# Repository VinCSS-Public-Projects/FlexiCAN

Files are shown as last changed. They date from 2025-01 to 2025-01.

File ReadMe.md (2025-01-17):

# FlexiCAN
The FlexiCAN device, developed by VinCSS, is an innovative automotive CAN solution designed for flexibility and ease of use. It features a unique software-controlled hot-swappable semiconductor switching matrix, enabling users to dynamically reconfigure the CAN_H and CAN_L pins of the CAN bus to any pin on the OBD-II port. This eliminates the need for proprietary connection cables, allowing seamless routing to non-standard or hidden CAN bus ports present on the OBD-II interface. Key highlights include software-configurable termination resistors (120Ω), support for CANFD up to 5 Mbit/s, and compatibility with both 11-bit (CAN 2.0A) and 29-bit (CAN 2.0B active) identifiers. The device supports high-speed CAN (ISO 11898-2 compliant) up to 1 Mbit/s and is fully compatible with Linux and CANSocket for robust integration. Its plug-and-play installation and fast, flexible command execution make it user-friendly, while the upcoming silent mode ensures non-intrusive analysis capabilities, making it ideal for automotive diagnostics and research applications.

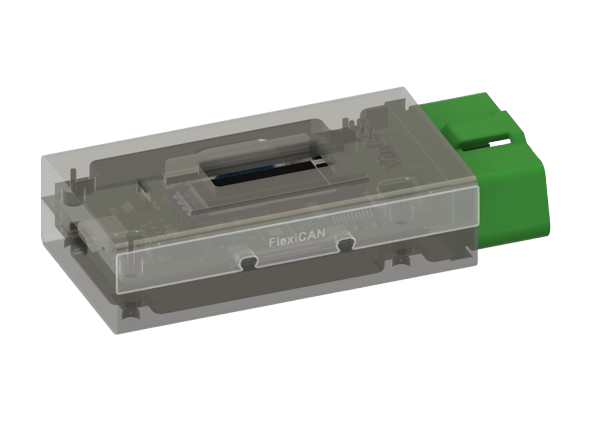
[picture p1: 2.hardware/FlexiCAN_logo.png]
FlexiCAN


# Key Features

• Flexibly Configure the Connection Between OBD-II and the CAN Device

• Software-configurable termination resistor (120Ω).

• Fast and flexible access to commands through COM

• Quick and straightforward plug-and-play installation.

• Supports CAN FD, with speeds up to 5 Mbit/s.

• Compatible with both 11-bit (CAN 2.0A) and 29-bit (CAN 2.0B active) identifiers.

• Fully compatible with Linux and CAN Socket.

• High-speed CAN connection (ISO 11898-2 compliant) with data rates up to 1 Mbit/s.

• Silent mode support for analysis tools – allows monitoring of the bus without interference (coming soon).

Full detail please check the document: [FlexiCAN-User-Manual-English.pdf](4.docs/FlexiCAN-User-Manual-English.pdf)
# Community & Support

We welcome contributions from the community! Please follow these steps:

1. Fork the repository.

2. Create a new branch (git checkout -b feature-branch-name).

3. Commit your changes (git commit -m "Description of changes").

4. Push to the branch (git push origin feature-branch-name).

5. Open a pull request.

If you encounter any problems, please open an issue. We will check and response as fast as possible.

## Hardware

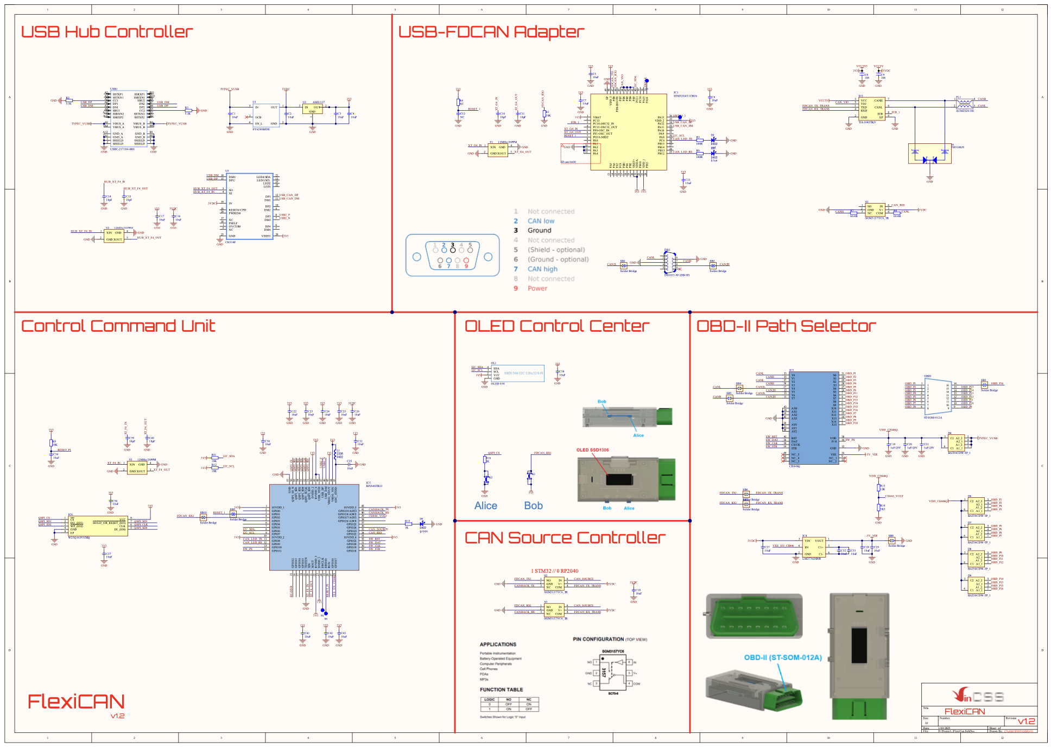
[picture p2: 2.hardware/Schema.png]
Schema


## Firmware

There are two controllers in FlexiCAN: RP2040 and STM32.

RP2040 is to control FlexiCAN & OBD-II switch.

STM32 is to control CAN interface

Source code of STM32 we use from this link https://github.com/candle-usb/candleLight_fw

# License 

FlexiCAN is fully open source.

All software, unless otherwise noted, is dual licensed under Apache 2.0 and MIT. You may use FlexiCAN software under the terms of either the Apache 2.0 license or MIT license.

All hardware, unless otherwise noted, is dual licensed under CERN and CC-BY-SA. You may use FlexiCAN hardware under the terms of either the CERN 1.2 license or CC-BY-SA 4.0 license.

THE SOFTWARE IS PROVIDED "AS IS", WITHOUT WARRANTY OF ANY KIND, EXPRESS OR IMPLIED, INCLUDING BUT NOT LIMITED TO THE WARRANTIES OF MERCHANTABILITY, FITNESS FOR A PARTICULAR PURPOSE AND NONINFRINGEMENT. IN NO EVENT SHALL THE AUTHORS OR COPYRIGHT HOLDERS BE LIABLE FOR ANY CLAIM, DAMAGES OR OTHER LIABILITY, WHETHER IN AN ACTION OF CONTRACT, TORT OR OTHERWISE, ARISING FROM, OUT OF OR IN CONNECTION WITH THE SOFTWARE OR THE USE OR OTHER DEALINGS IN THE SOFTWARE.

# Acknowledgment

FlexiCAN is built upon the foundation of many other excellent open-source projects. We would like to express our gratitude to the following contributors:

Thank you [@sakumisu](https://github.com/sakumisu) for the projects:
- [CherryShell](https://github.com/cherry-embedded/CherrySH), a tiny shell specifically designed for embedded applications.
- [CherryUSB](https://github.com/cherry-embedded/CherryUSB), a tiny, beautiful, and portable USB host and device stack for embedded systems with USB IP.

Thank you [@Egahp](https://github.com/Egahp) for the [CherryRingBuffer](https://github.com/cherry-embedded/CherryRB) project, an efficient and easy-to-use ring buffer, especially with DMA support

Thank you [@marckleinebudde](https://github.com/marckleinebudde) and the [candleLight](https://github.com/candle-usb/candleLight_fw) development team for creating such an incredibly useful project

# Ethical and Responsible Use

This tool, FlexiCAN, is developed for educational and ethical testing purposes only.  Any misuse or illegal use of this tool is strictly prohibited. The creator of FlexiCAN  assumes no liability and is not responsible for any misuse or damage caused by this tool. 
Users are required to comply with all applicable laws and regulations in their jurisdiction regarding network testing and ethical hacking.

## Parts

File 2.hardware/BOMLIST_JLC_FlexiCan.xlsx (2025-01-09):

Comment | Description | Designator | Footprint | LibRef | Quantity | JLCPCB Part #
10uF | Capacitor | C1, C2, C3, C4, C5, C6, C7, C13, C16, C17, C18, C22, C23, C24, C25, C26, C27, C28, C29, C30, C31, C32, C33, C34, C35, C36, C37, C38, C41, C42, C43 | CAP_0402 | C_0402 | 31 | C15525
104 | Cap SMD | C8, C9 | CAP_0402 | CM | 2 | C1525
18pF | Capacitor | C10, C11, C14, C15, C39, C40 | CAP_0402 | C_0402 | 6 | C1549
NC | Capacitor | C12 | CAP_0402 | C_0402 | 1 | no soldering
1uF/25V | Capacitor | C19, C20, C21 | CAP_0402 | C_0402 | 3 | C52923
red | LED | D1 | LED_0402_RED | LED_0402 | 1 | C264407
blue | LED | D2 | LED_0402_BLUE | LED_0402 | 1 | C131223
PESD1CAN,215 | TVS DIODE 5V 14V SOT23 | D3 | SOT23-3 | PESD5V0S2BT,215 | 1 | C15771
BAT54CDW-TP_1 | Schottky Diode | D4, D6, D7, D8, D9 | SOT65P222X120-6N | BAT54CDW-TP_1 | 5 | C5240639
green | LED | D5 | LED_0402_GREEN | LED_0402 | 1 | C20613596
DS1033-9F (DB-9F) | DS1033-9F (DB-9F) Female | DB1 | DB-9 DS1033-9F | DB9-F | 1 | C3020564
ACM2520-301 | Common Mode Filters | FL1 | ACM25203012P | ACM2520-301-2PL-TL01_1 | 1 | C76577
STM32G431CBU6 | Integrated Circuit | IC1 | QFN50P700X700X65-49N-D | STM32G431CBU6 | 1 | C529356
TJA1042TK/3 | https://item.taobao.com/item.htm?id=715328337189&ns=1&abbucket=13 | IC2 | SON65P300X300X100-9N | SIT1044QTK/3 | 1 | C131480
CH446Q | Integrated Circuit | IC3 | QFP80P1350X1350X150-44N | CH446Q | 1 | C109471
LM2776DBVR | Integrated Circuit | IC4 | SOT95P280X145-6N | LM2776DBVR | 1 | C69527
RP2040TR13 | Integrated Circuit | IC5 | RP2040TR13 | RP2040TR13 | 1 | C2040
W25Q16JVUXIQ | Integrated Circuit | IC6 | SON50P300X200X60-9N | W25Q16JVUXIQ | 1 | C2843335
TACT 4P | Button | K1, K2 | ButtonTACT_3.5*3.55_90 | ButtonTACT | 2 | C79167
H0402 | Inductor | L1 | IND_0402Q | Ind_0402 | 1 | C14709
ST-SOM-012A | ST-SOM-012A OBD II Connector | OBD1 | ST-SOM-012A | ST-SOM-012A | 1 | https://www.setolink.com/pcb-obdii-16-pin-male-connector-core-st-som012a.html
OLED 0.91 | HS HS91L02W2C01 SSD1306 I2C 128x32 0.91 - Organic Light Emitting Diode Display Screen ROHS | OL1 | OLED 0.91 I2C | OLED 0.91 128*32 | 1 | C5248081
10K | Resistor R1/4W, Resistor | R1, R9, R11, R12 | RES_0402 | R, R-0402 | 4 | C25744
5.1K | Resistor | R2, R3 | RES_0402 | R-0402 | 2 | C25905
NC | Resistor | R4 | RES_0402 | R-0402 | 1 | no soldering
1K | Resistor R1/4W, Resistor | R5, R6, R10, R15 | RES_0402 | R, R-0402 | 4 | C11702
60.4R | Resistor | R7, R8 | RES_0402 | R-0402 | 2 | C60310
12K | Resistor R1/4W | R13 | RES_0402 | R | 1 | C25752
3K3 | Resistor R1/4W | R14 | RES_0402 | R | 1 | C25890
SGM3157YC6_TR | Switch | S1, S2, S3 | SOT65P230X110-6N | SGM3157YC6_TR | 3 | C394901
SY6288B/D/E | SY6288B/D/E Active Low | U1 | SOT95P285X130-5N | SY6288_EN_L | 1 | C83700
AMS1117 |  | U2 | SOT223 | AMS117 | 1 | C6186
CH334F | CH334F Hub USB C5187527 | U3 | QFN50P400X400X80-25N-D | CH334F | 1 | C5187527
USBC-217184-0001 | USB-C (USB TYPE-C) USB 3.2 Gen 2 (USB 3.1 Gen 2, Superspeed + (USB 3.1)) Receptacle Connector 24 Position Surface Mount, Right Angle; Through Hole | USB1 | Molex_217184-0001 | USBC-217184-0001 | 1 | C2874575
12MHz/20PPM | XT-2520 | Y1, Y2, Y3 | XT-2520 | XT-4Pin | 3 | C2896601

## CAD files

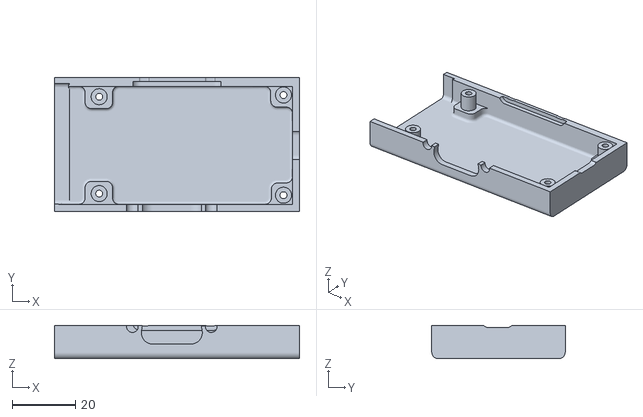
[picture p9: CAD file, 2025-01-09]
3.model/FlexiCan_3D_bottom.stl
77.6 x 42.3 x 10.5

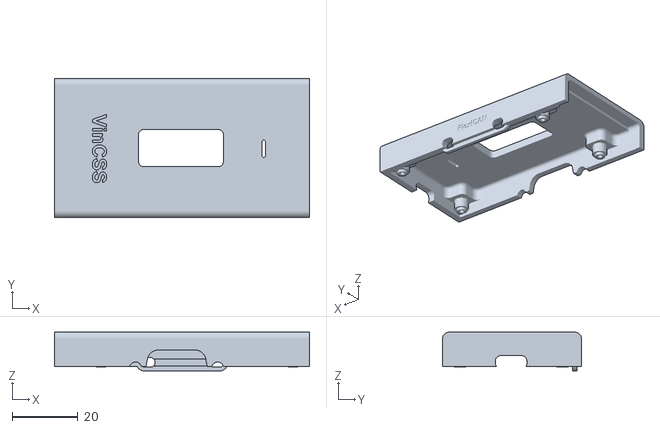
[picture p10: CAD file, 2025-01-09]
3.model/FlexiCan_3D_top.stl
77.6 x 42.3 x 11.8

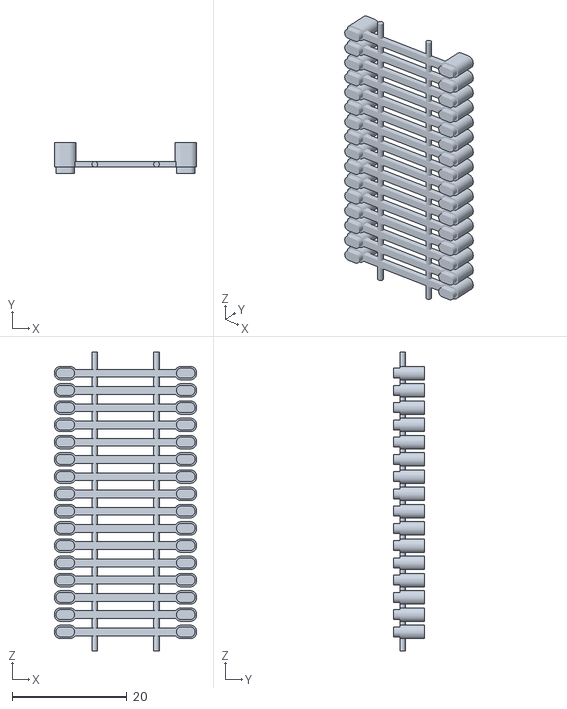
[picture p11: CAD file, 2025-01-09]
3.model/FlexiCan_3D_button.stl
24.8 x 5.40 x 52.0

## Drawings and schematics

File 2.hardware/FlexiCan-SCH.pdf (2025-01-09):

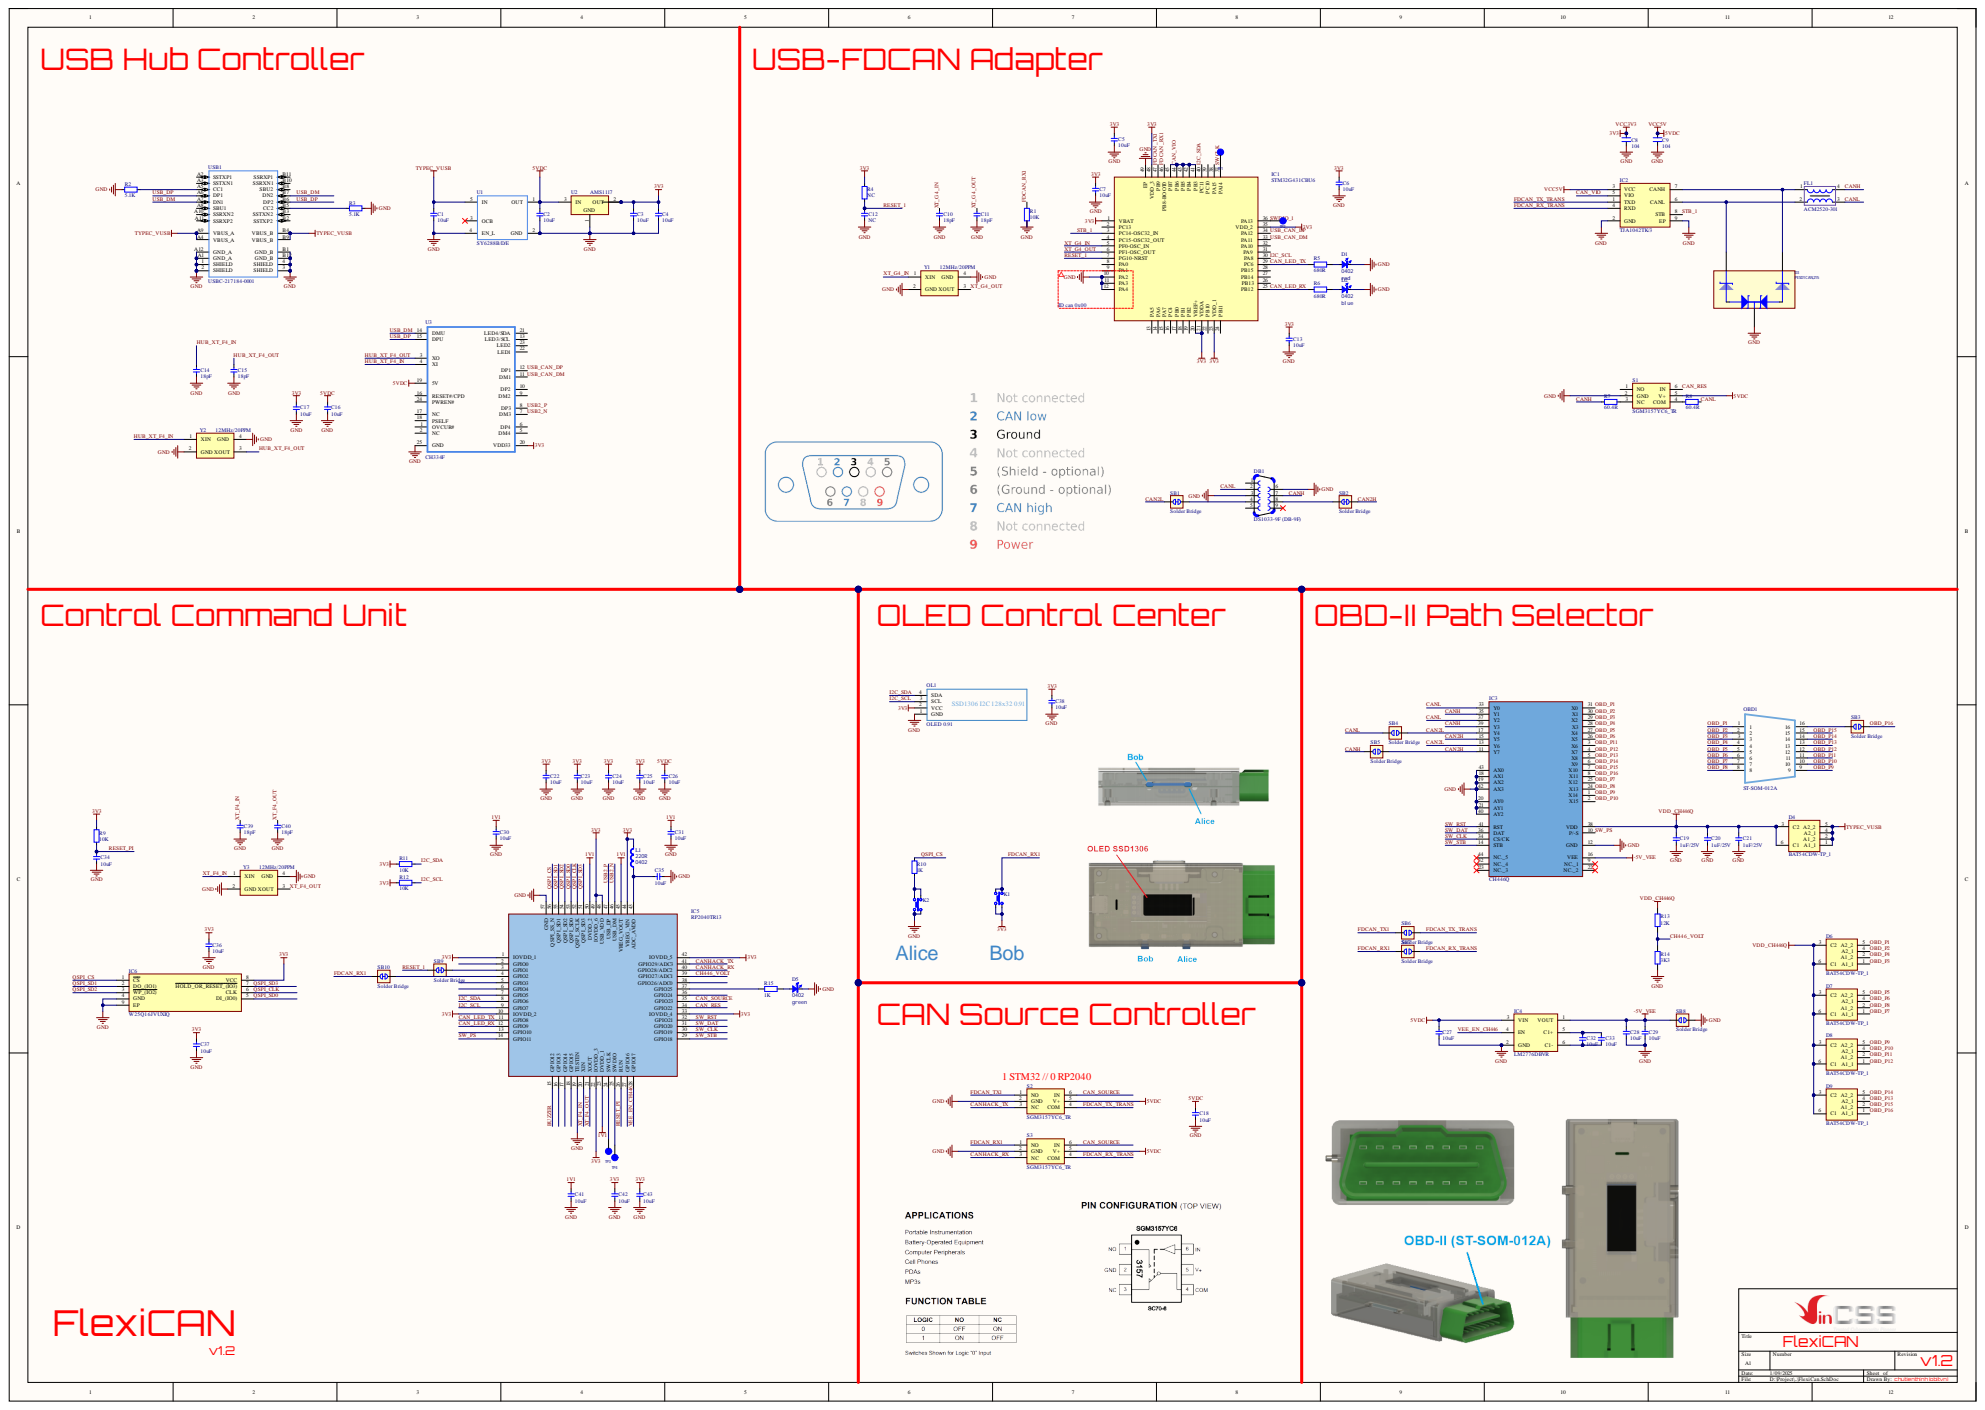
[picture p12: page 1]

OBD-II Path Selector

CANHACK_TX | NC 3 | FDCAN_TX_TRANS

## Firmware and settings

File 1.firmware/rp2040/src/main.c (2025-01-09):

#include "hardware/gpio.h"
#include "hardware/structs/io_bank0.h"
#include "pico/binary_info.h"
#include "hardware/i2c.h"
#include "pindef.h"
#include "utils.h"
#include "ssd1306.h"
#include "storage.h"
#include "shell.h"
#include "menu.h"
#include "ch446q.h"
#include <string.h>

/*
 *  Logical Diagram
 *
 *         [Computer]
 *              ^
 *              |
 *    ------>[USB Hub]
 *   |          |
 *   |          |  _____________________________________
 *   |          | |                                     |
 *   |          | |                                     |
 *   |          | |  [OLED Display]                     |
 *   |          | |      /                              |
 *   |          | |     /                               |
 *   |          | |   I2C                               |
 *   |          | |   /                                 |
 *   |          v v  /                               GPIO control
 *   |      ->[RP2040] <-- SPI --> [Flash 2M]           |
 *   |     |     ^    \                                 |
 *   |     |     |     \                                |
 *   |   BOOT   I2C     \                               |
 *   |     |     |       \                              |
 *   |     v     v        \                             v
 *    --->[STM32...]<-->[CAN Transceiver] <--------> [CH446Q] <----> [OBD-II]
 *
 * */

// global variables
ssd1306_t g_display;
storage_t g_storage;
uint8_t g_reload_CH446Q_setting = 1;
uint8_t g_CAN_high_pin[MAX_NUM_PINS] = {0}, g_CAN_low_pin[MAX_NUM_PINS] = {0};


// functions
void init_default_pins()
{
  // setup control boot for STM32
  // Set STM32 PB8_BOOT0 to 0 to enable STM32 boot from its main Flash Memory
  gpio_init(GPIO_RP_STM_BOOT0);
  gpio_put(GPIO_RP_STM_BOOT0, 0);
  gpio_pull_down(GPIO_RP_STM_BOOT0);
  gpio_set_dir(GPIO_RP_STM_BOOT0, GPIO_OUT);
  gpio_put(GPIO_RP_STM_BOOT0, 0);

  gpio_init(GPIO_RP_STM_RST);
  gpio_set_dir(GPIO_RP_STM_RST, GPIO_OUT);
  gpio_put(GPIO_RP_STM_RST, 1);
  delay_ms(2);
  // keep stm32 reset
  gpio_put(GPIO_RP_STM_RST, 0);
  delay_ms(2);

  gpio_deinit(GPIO_RP_STM_BOOT0);
  // end setup control dfu mode of STM32

  // set CAN TX/RX for RP2040. 0 = RP2040, 1 = STM32
  gpio_init(GPIO_CAN_SOURCE);
  gpio_set_dir(GPIO_CAN_SOURCE, GPIO_OUT); 
  gpio_put(GPIO_CAN_SOURCE, 1);
  
  gpio_init(GPIO_CAN_HACK_RX);
  gpio_init(GPIO_CAN_HACK_TX);
  gpio_set_dir(GPIO_CAN_HACK_RX, GPIO_IN);// just set GPIO_IN to avoid any inferrence to CAN. If we need send out data, need to re-initilize it to GPIO_OUT
  gpio_set_dir(GPIO_CAN_HACK_TX, GPIO_IN);
  // end CAN TX/RX for RP2040

  //start STM32 again
  gpio_put(GPIO_RP_STM_RST, 1);
  delay_ms(2);
  gpio_set_dir(GPIO_RP_STM_RST, GPIO_IN);
  gpio_pull_up(GPIO_RP_STM_RST);
}

void init_oled_display()
{
  // baurate 100000
  i2c_init(GPIO_I2C_PORT, 100 * 1000);
  gpio_set_function(GPIO_I2C_SDA, GPIO_FUNC_I2C);
  gpio_set_function(GPIO_I2C_SCL, GPIO_FUNC_I2C);
  gpio_pull_up(GPIO_I2C_SDA);
  gpio_pull_up(GPIO_I2C_SCL);
  bi_decl(bi_2pins_with_func(GPIO_I2C_SDA, GPIO_I2C_SCL, GPIO_FUNC_I2C));
  g_display.external_vcc = 0;
  ssd1306_init(&g_display, OLED_WIDTH, OLED_HEIGHT, I2C_ADDR, GPIO_I2C_PORT);
  ssd1306_clear(&g_display);
}

void init_storage()
{
  storage_read(&g_storage);
}

void init_CH446Q()
{
  CH446Q_init();
}

void logo()
{
  ssd1306_clear(&g_display);
  ssd1306_draw_string(&g_display, 7, 10, 3, "VinCSS");
  ssd1306_show(&g_display);
}

void load_current_CAN_config()
{
  for (int i = 0; i < g_storage.num_of_profiles; i++)
  {
    if (g_storage.profiles[i].status == ACTIVE)
    {
      memcpy(g_CAN_high_pin, g_storage.profiles[i].can_high_pin, 
                    MAX_NUM_PINS * sizeof(uint8_t));
      memcpy(g_CAN_low_pin, g_storage.profiles[i].can_low_pin, 
                    MAX_NUM_PINS * sizeof(uint8_t));
      break;
    }
  }
}

int main()
{
  uint32_t refresh_counter = 0;
  init_default_pins();
  init_oled_display();
  init_storage();
  init_CH446Q();

  if (g_storage.is_first_run)
  {
    set_default_storage(&g_storage);
    storage_write(&g_storage);
  }

  shell_init(&g_storage);

  logo();
  delay_ms(1000);
  //load current active profile;
  load_current_CAN_config();
  CH446Q_reset();
  CH446q_refresh();
  
  while (1)
  {
    shell_main();
    menu();
    refresh_counter++;
    delay_us(100);
    if(refresh_counter % 1000000){ //100s refresh one time
      CH446q_refresh();
      refresh_counter++;
    }
  }
}

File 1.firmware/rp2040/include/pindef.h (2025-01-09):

#ifndef __PIN_DEF__
#define __PIN_DEF__

#ifdef __cplusplus
extern "C"
{
#endif

// hold pin definition of Flexican device
// GPIOs to control dfu mode of STM32
#define GPIO_RP_STM_RST 1
#define GPIO_RP_STM_BOOT0 2
#define GPIO_BUTTON_K1 2

// GPIOs to control OLED screen
#define GPIO_I2C_PORT i2c1
#define GPIO_I2C_SDA 6
#define GPIO_I2C_SCL 7
#define OLED_WIDTH 128
#define OLED_HEIGHT 32
#define I2C_ADDR 0x3c

// GPIOs to control led TX/RX
#define GPIO_CAN_LED_TX 8
#define GPIO_CAN_LED_RX 9

// GPIOs to control CH466
#define GPIO_SW_PS 11
#define GPIO_SW_RST 21
#define GPIO_SW_DAT 20
#define GPIO_SW_CLK 19
#define GPIO_SW_STB 18

// GPIO to control CAN source either from RP or STM32
#define GPIO_CAN_SOURCE 23
// GPIO for control 120Ohm for CAN
#define GPIO_CAN_RES 22

#define GPIO_CAN_HACK_TX 29
#define GPIO_CAN_HACK_RX 28

// protected volt for C446
#define GPIO_CH446_VEE 17
#define GPIO_CH446_VOLT 27

// RP led
#define GPIO_LED 25

#ifdef __cplusplus
} /*extern "C"*/
#endif

#endif

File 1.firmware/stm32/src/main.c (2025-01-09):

/*

The MIT License (MIT)

Copyright (c) 2016 Hubert Denkmair

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
*/

#include <stdbool.h>
#include <stdint.h>
#include <stdlib.h>

#include "board.h"
#include "can.h"
#include "can_common.h"
#include "config.h"
#include "device.h"
#include "dfu.h"
#include "gpio.h"
#include "gs_usb.h"
#include "hal_include.h"
#include "led.h"
#include "timer.h"
#include "usbd_conf.h"
#include "usbd_core.h"
#include "usbd_def.h"
#include "usbd_desc.h"
#include "usbd_gs_can.h"
#include "util.h"

static USBD_GS_CAN_HandleTypeDef hGS_CAN;
static USBD_HandleTypeDef hUSB = {0};

static void DisableUSBSOFInterrupt(USBD_HandleTypeDef *pdev)
{
#if defined(USB) || defined(USB_DRD_FS)
	// F0, G0 and G4 do not respect sof_enable field in their init structures
	PCD_HandleTypeDef *pcd = (PCD_HandleTypeDef*)pdev->pData;

#if defined(USB_DRD_FS)
	// G0
	USB_DRD_TypeDef *usb = pcd->Instance;
#else
	// F0 and G4
	USB_TypeDef *usb = pcd->Instance;
#endif

	usb->CNTR &= ~(USB_CNTR_SOFM | USB_CNTR_ESOFM);
#else
	(void)pdev;
#endif
}

int main(void)
{
	HAL_Init();
	device_sysclock_config();

	config.setup(&hGS_CAN);
	timer_init();

	INIT_LIST_HEAD(&hGS_CAN.list_frame_pool);
	INIT_LIST_HEAD(&hGS_CAN.list_to_host);

	for (unsigned i = 0; i < ARRAY_SIZE(hGS_CAN.msgbuf); i++) {
		list_add_tail(&hGS_CAN.msgbuf[i].list, &hGS_CAN.list_frame_pool);
	}

	for (unsigned int i = 0; i < ARRAY_SIZE(hGS_CAN.channels); i++) {
		const struct BoardChannelConfig *channel_config = &config.channels[i];
		const struct LEDConfig *led_config = channel_config->leds;
		can_data_t *channel = &hGS_CAN.channels[i];

		channel->nr = i;

		INIT_LIST_HEAD(&channel->list_from_host);

		led_init(&channel->leds,
				 led_config[LED_RX].port, led_config[LED_RX].pin, led_config[LED_RX].active_high, led_config[LED_RX].invert,
				 led_config[LED_TX].port, led_config[LED_TX].pin, led_config[LED_TX].active_high, led_config[LED_TX].invert);

		/* nice wake-up pattern */
		for (uint8_t j = 0; j < 200; j++) {
			HAL_GPIO_TogglePin(led_config[LED_RX].port, led_config[LED_RX].pin);
			HAL_Delay(1);
			HAL_GPIO_TogglePin(led_config[LED_TX].port, led_config[LED_TX].pin);
		}

		led_set_mode(&channel->leds, LED_MODE_OFF);

		can_init(channel, config.channels[i].interface);
		can_disable(channel);
	}

	USBD_Init(&hUSB, (USBD_DescriptorsTypeDef*)&FS_Desc, DEVICE_FS);
	USBD_RegisterClass(&hUSB, &USBD_GS_CAN);
	USBD_GS_CAN_Init(&hGS_CAN, &hUSB);
	USBD_Start(&hUSB);
	DisableUSBSOFInterrupt(&hUSB);

	while (1) {

		USBD_GS_CAN_SendReceiveFromHost(&hUSB);

		for (unsigned int i = 0; i < ARRAY_SIZE(hGS_CAN.channels); i++) {
			can_data_t *channel = &hGS_CAN.channels[i];

			CAN_SendFrame(&hGS_CAN, channel);
			CAN_ReceiveFrame(&hGS_CAN, channel);
			CAN_HandleError(&hGS_CAN, channel);

			led_update(&channel->leds);
		}

		if (USBD_GS_CAN_DfuDetachRequested(&hUSB)) {
			dfu_run_bootloader();
		}

		if (config.mainloop_callback) config.mainloop_callback();
	}
}

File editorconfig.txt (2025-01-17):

# EditorConfig is awesome: https://EditorConfig.org

# Extras : to configure git's pager for tab with of 4:
# $ git config core.pager 'less -x1,5'
#
# to configure optional text mode interface tig:
# $ git config tig.tab-size '2'

# top-most EditorConfig file
root = true

# Unix-style newlines with a newline ending every file
[*]
end_of_line = lf
indent_size = 2
indent_style = space
insert_final_newline = true
trim_trailing_whitespace = true

[*.yml]
indent_size = 2
indent_style = space

[lib/**]
indent_size = 2
indent_style = space

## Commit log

2025-01-09 Init FlexiCAN
    [BOMLIST_JLC_FlexiCan.xlsx, FlexiCan.SchDoc, PCB_FlexiCan.PrjPcb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]
2025-01-09 Update 3d model
    [FlexiCan_3D_bottom.stl, FlexiCan_3D_button.stl, FlexiCan_3D_top.stl]
2025-01-09 Update folder name
    [BOMLIST_JLC_FlexiCan.xlsx, FlexiCan.SchDoc, FlexiCan_3D_bottom.stl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]
2025-01-17 Add license files
    [editorconfig.txt]
